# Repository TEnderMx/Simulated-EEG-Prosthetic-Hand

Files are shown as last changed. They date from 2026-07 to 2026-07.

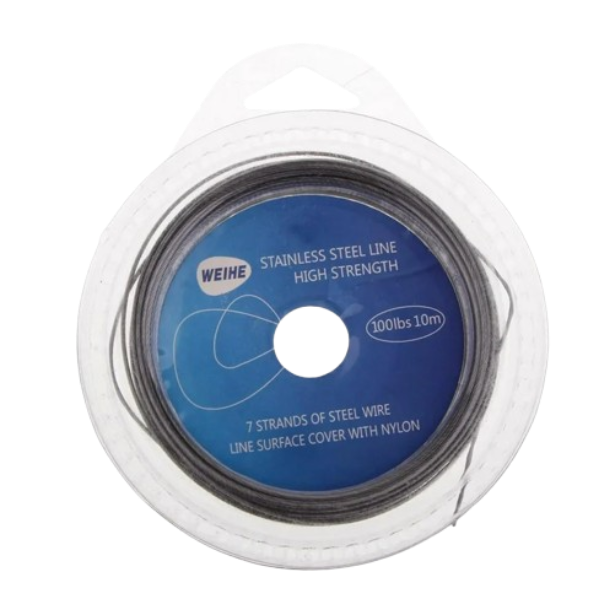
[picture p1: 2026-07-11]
Gallery/line.png

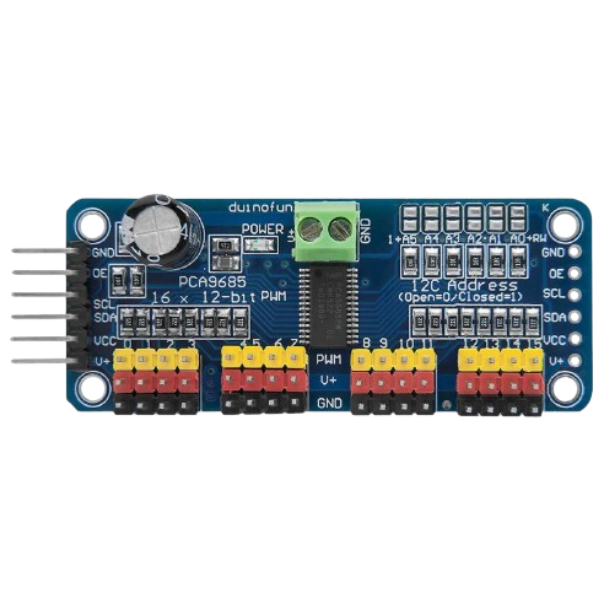
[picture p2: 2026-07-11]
Gallery/servocont.png

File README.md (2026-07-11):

<div align="center">

# 🧠 Simulated EEG BCI-Controlled Prosthetic Hand
**Translating Brain Signals into Physical Movement (Simulation Approach)**

[]()
[]()
[]()

*A Senior Graduation Project — Misr University for Science & Technology (MUST)*
<br>Faculty of Engineering | Biomedical Engineering Department

</div>

---

## 📖 Overview
This project introduces a **simulated Brain–Computer Interface (BCI)** system designed to assist upper-limb amputees. By decoding simulated neural activity, the system translates Motor Imagery (MI) into physical movement commands. The core innovation lies in a high-accuracy **MATLAB Signal Processing Pipeline** integrated with an **Artificial Neural Network (ANN)**, which drives a low-cost, high-torque prosthetic assembly via an Arduino UNO controller.

> **Note on Implementation:** Due to a technical malfunction with the planned EEG device preventing real signal acquisition, we adapted the project to use a highly sophisticated simulated BCI approach. This allowed us to maintain the complete software and hardware pipeline while simulating the neural input.

---

## ⚙️ Simulated System Architecture
To simulate the BCI input accurately, we integrated several advanced open-source tools to generate and stream neural-like data:

1. **Simulated Data Acquisition (MediaPipe):** We used Google's MediaPipe Hand Landmarker to capture 21 hand key points via camera tracking. This behavioral data acts as the basis for our simulated motor intentions.
2. **Simulated Data Processing (Neural Data Simulator - NDS):** We utilized the [Neural Data Simulator (NDS)](https://github.com/agencyenterprise/neural-data-simulator), an open-source Python package designed to generate real-time electrophysiology data. NDS translates the kinematics from MediaPipe into simulated 14-channel EEG-like waveforms (AF3, F7, F3, FC5, T7, P7, O1, O2, P8, T8, FC6, F4, F8, AF4).
3. **Data Streaming (Lab Streaming Layer - LSL):** The simulated neural data is streamed in real-time to MATLAB using [liblsl-Matlab](https://github.com/labstreaminglayer/liblsl-Matlab), effectively bridging the simulated signal source and our processing hub.
4. **Processing & Decoding (MATLAB):** MATLAB receives the LSL stream, processes the signals, and uses a Multi-layer Perceptron (MLP) Artificial Neural Network to classify the motor imagery.
5. **Actuation (Arduino & Hardware):** Classified commands are sent via Serial to an Arduino Uno, which drives high-torque metal gear servos (MG996R) using PWM to articulate the 3D-printed fingers.

---

## 🧠 Neural Network Performance
Our Artificial Neural Network (ANN) was trained using a back-propagation algorithm to map the complex, non-linear relationships of the simulated EEG features:
- **Average Classification Accuracy:** 82.1%
- **Training Convergence:** Demonstrated a consistent decline in Mean Squared Error (MSE) across epochs, indicating successful learning without overfitting.
- **Regression Analysis:** Achieved stable R-values across Training, Validation, and Testing phases, proving a strong correlation between targets and outputs.
- **Error Distribution:** Normal distribution of errors around zero, confirming the model is unbiased toward any specific output class.

---

## 🛠️ Hardware Integration
- **Microcontroller:** Arduino Uno R3 (ATmega328P, 16 MHz)
- **Actuators:** MG996R Metal Gear Servo Motors (11 kg/cm torque at 6V, 180° rotation)
- **Prosthetic Hand Design:** A lightweight, 3D-printed PLA assembly utilizing a bio-mimetic tendon-like structure. Nylon tension strings handle flexion, while a spring-return mechanism manages extension.

---

## 🚀 Future Roadmap
Our project successfully demonstrates a full-loop BCI solution (via simulation) translating neural motor imagery into mechanical grasping. To advance this foundation, we plan the following:
- [ ] **Real EEG Integration:** Transition from simulated data back to live EEG acquisition.
- [ ] **Sensory Feedback:** Integrate pressure sensors for tactile sensation.
- [ ] **Deep Learning:** Transition to LSTM networks for time-series optimization.
- [ ] **Portability:** Replace the PC processing hub with a Raspberry Pi for standalone use.
- [ ] **Cloud Integration:** Implement remote monitoring and subject training data logs.

---

## 👥 The Team
**Supervisor:** Dr. Islam A. Foad

---

## Special Credits and Huge Thanks to these amazing people:
**NDS:** https://github.com/agencyenterprise/neural-data-simulator/

**liblsl-Matlab:** https://github.com/labstreaminglayer/liblsl-Matlab/

**Prosthetic Hand Design:** https://inmoov.fr/

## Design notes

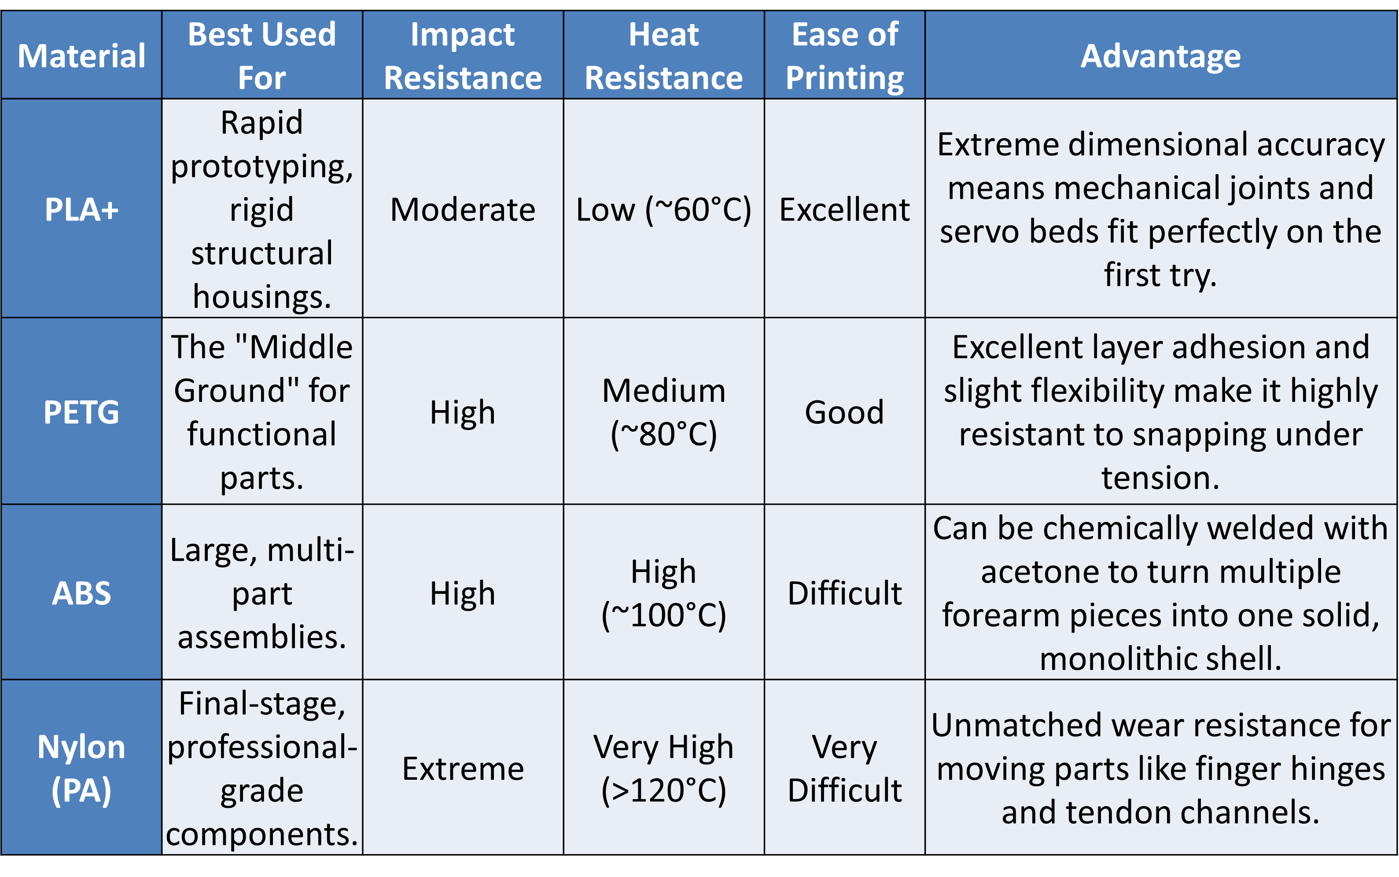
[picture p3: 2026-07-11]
Gallery/Picture4.png

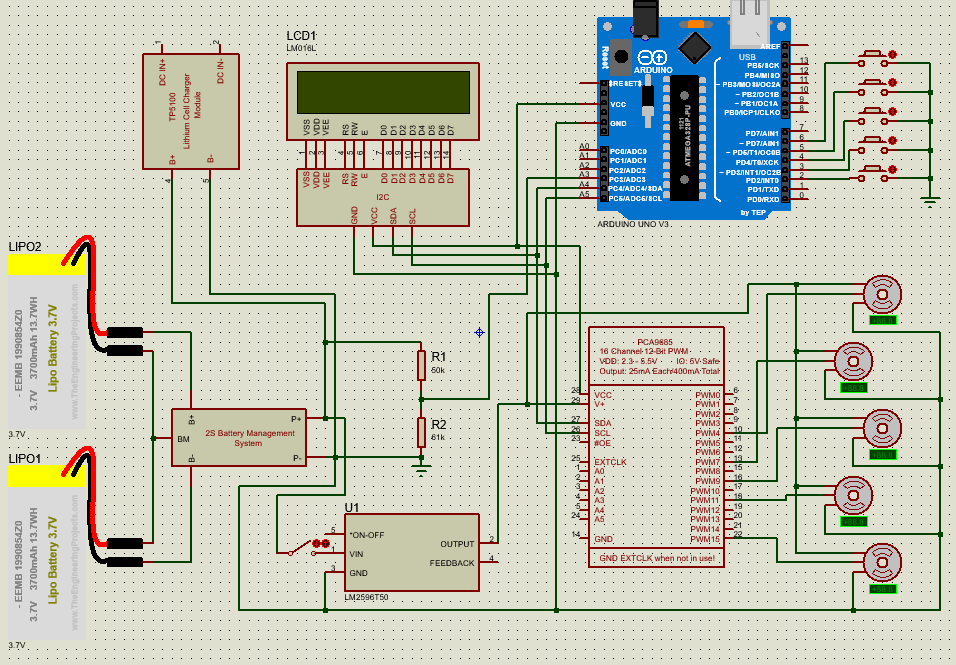
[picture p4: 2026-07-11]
Gallery/Circuit Diagram.png

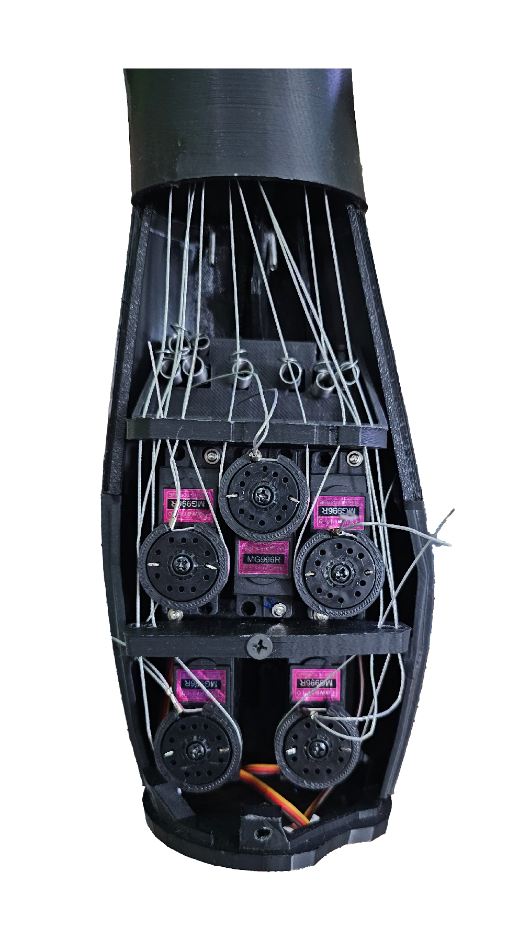
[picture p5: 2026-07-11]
Gallery/20260223_234325~1.png

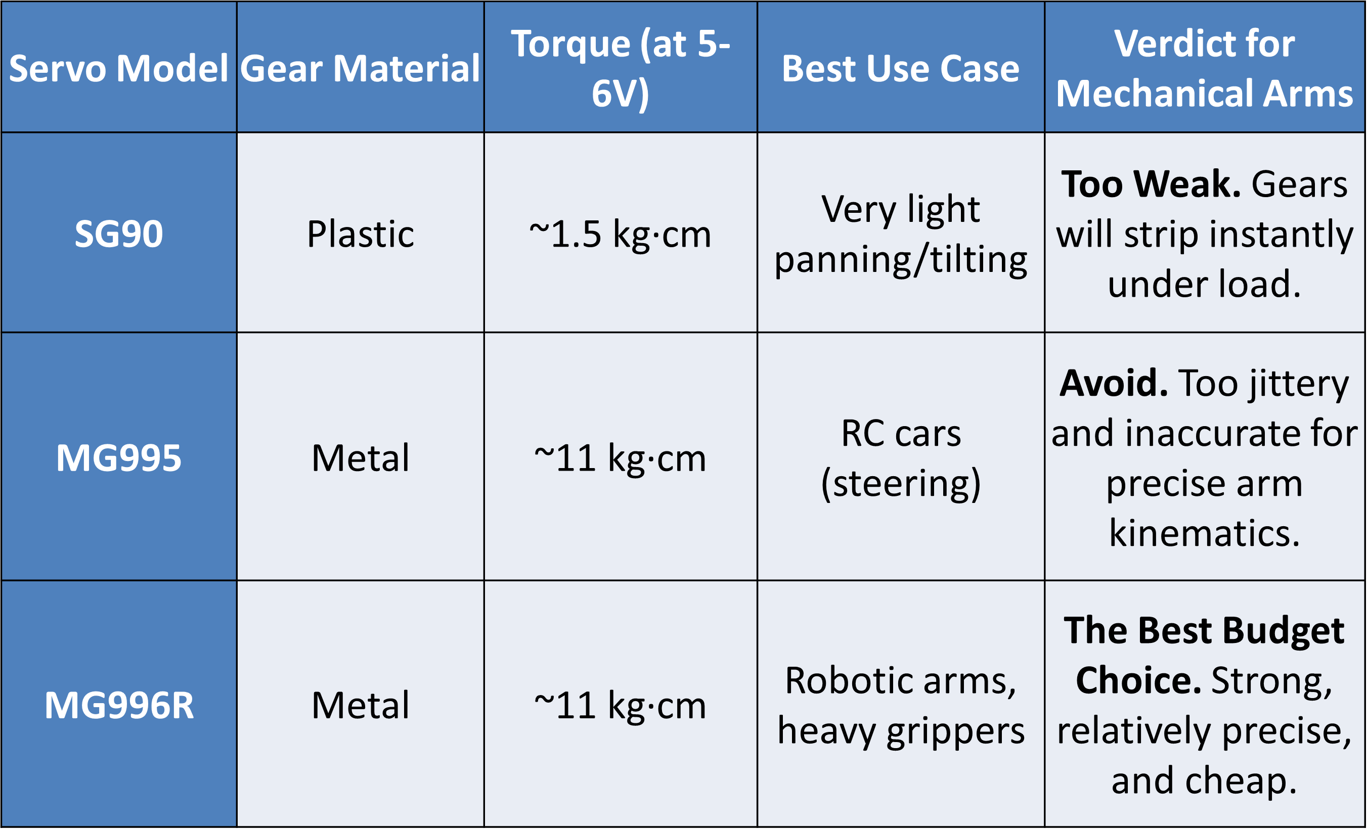
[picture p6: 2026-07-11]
Gallery/Picture3.png

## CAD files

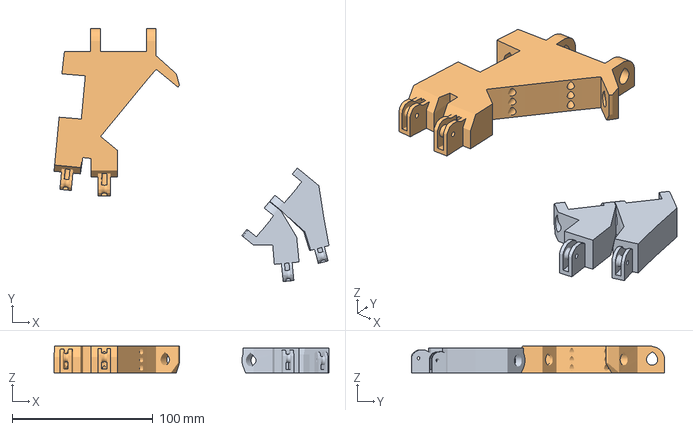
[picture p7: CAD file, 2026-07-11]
Hardware/3D Printer Files/Bambu Labs Files/Wrist.3mf
195.6 x 180.1 x 18.9 mm
WristsmallV4.stl
WristlargeV4.stl

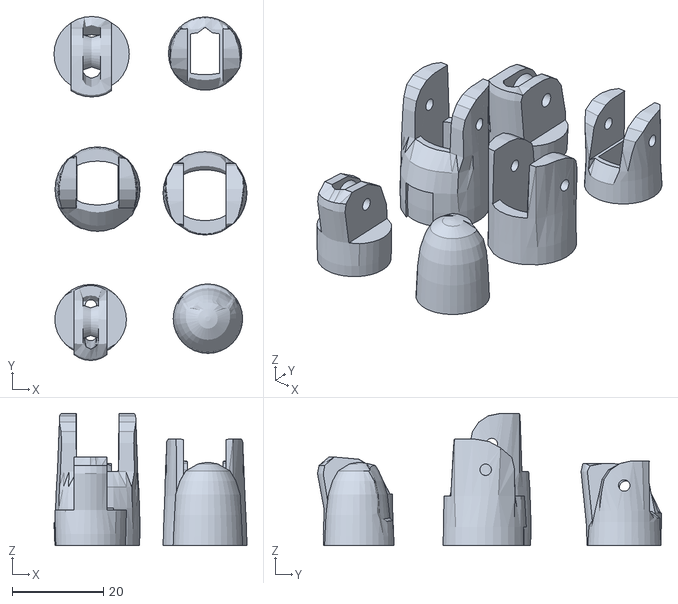
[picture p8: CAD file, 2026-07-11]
Hardware/3D Printer Files/Majeure3.stl
42.2 x 75.2 x 29.0

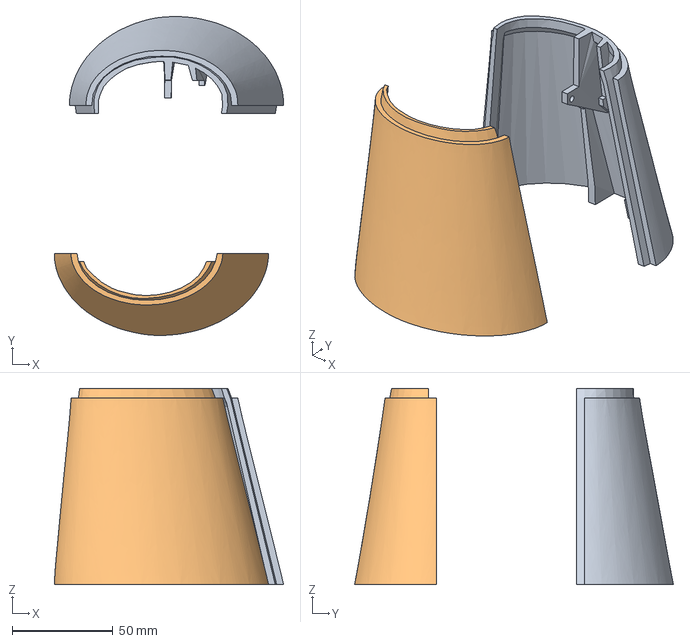
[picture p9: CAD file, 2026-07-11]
Hardware/3D Printer Files/Bambu Labs Files/Arm1.3mf
113.8 x 158.3 x 97.5 mm
robpart2V4.stl
robpart3V4.stl

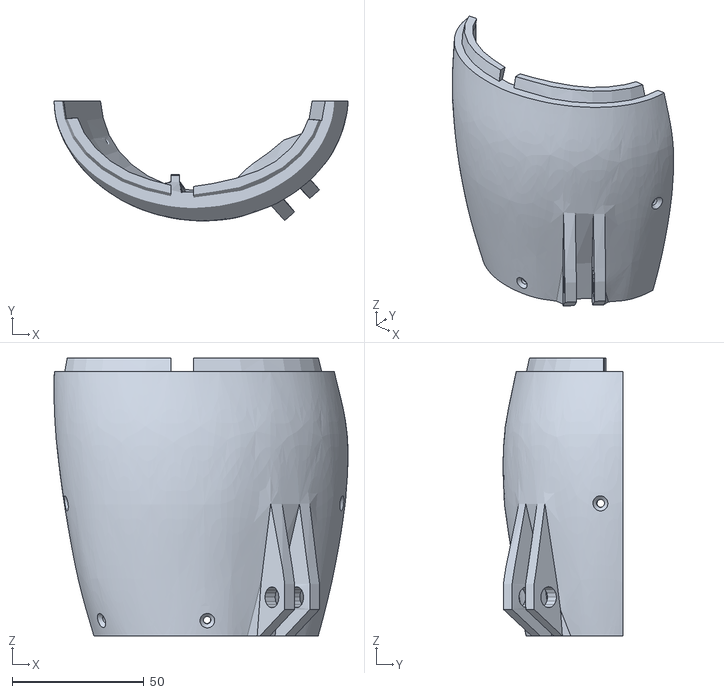
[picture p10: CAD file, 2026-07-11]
Hardware/3D Printer Files/robpart4V4.stl
111.8 x 45.5 x 105.6

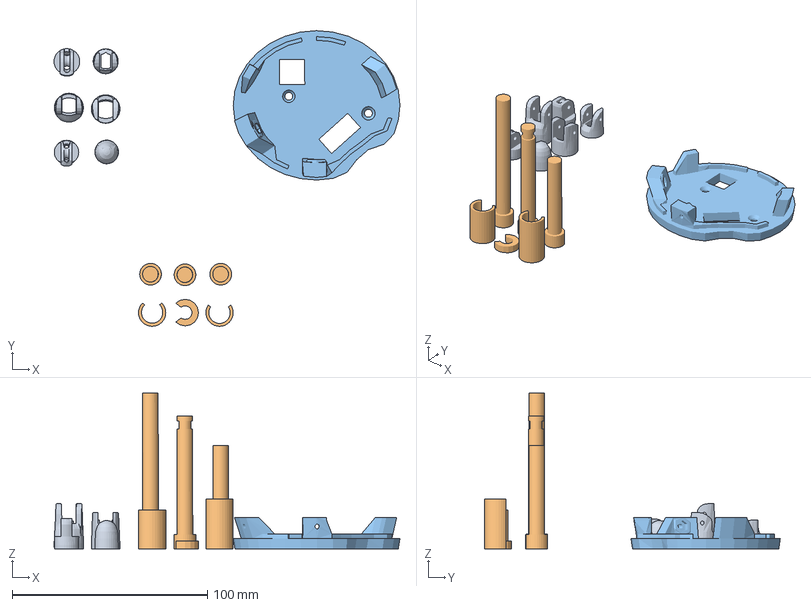
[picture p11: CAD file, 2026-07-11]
Hardware/3D Printer Files/Bambu Labs Files/Fingers2+ArmCap.3mf
177.3 x 151.5 x 79.9 mm
Auriculaire3.stl
Bolt_entretoise7.stl
robcap3V2.stl

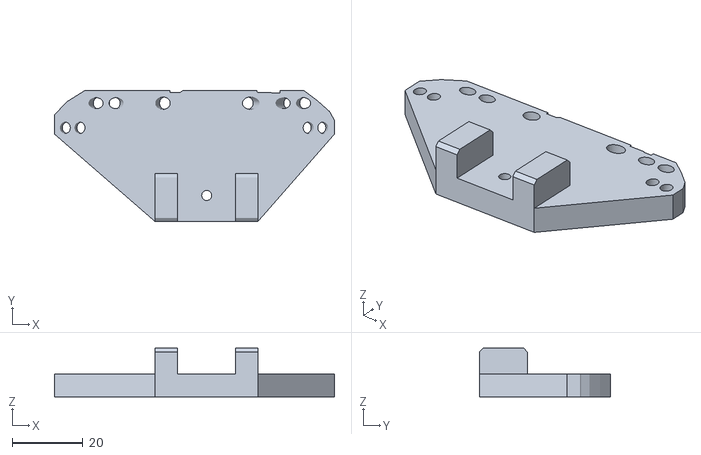
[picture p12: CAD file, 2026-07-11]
Hardware/3D Printer Files/RobCableFrontV3.stl
79.3 x 37.1 x 13.8

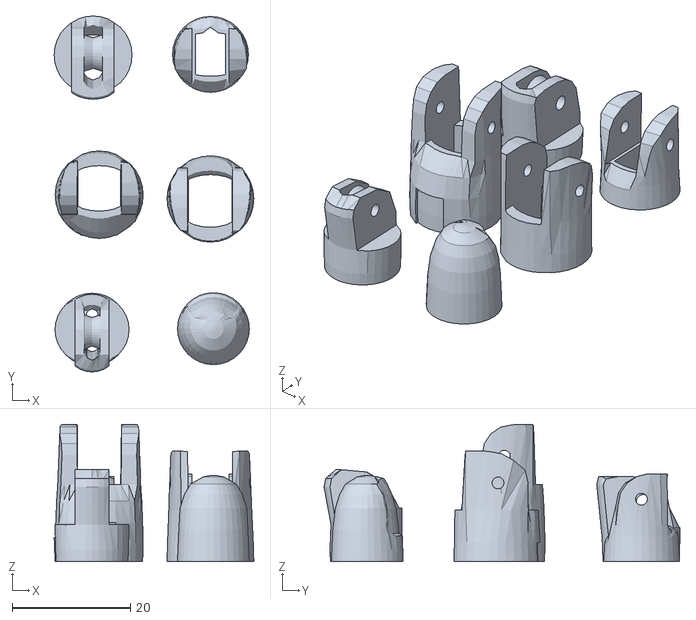
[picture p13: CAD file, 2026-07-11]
Hardware/3D Printer Files/Auriculaire3.stl
33.8 x 60.3 x 23.2

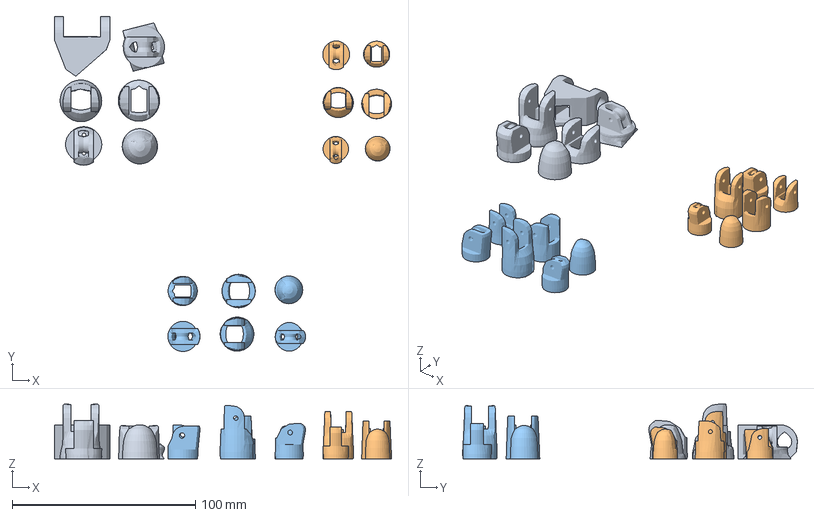
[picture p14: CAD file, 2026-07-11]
Hardware/3D Printer Files/Bambu Labs Files/Fingers1.3mf
184.1 x 182.9 x 29.8 mm
thumb5.stl
ringfinger3.stl
Majeure3.stl

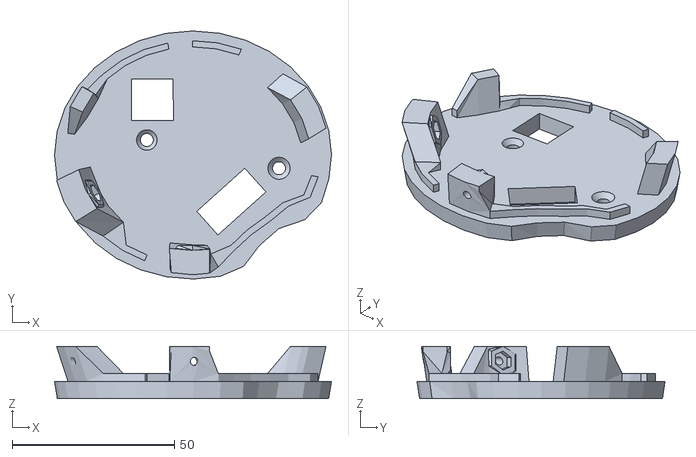
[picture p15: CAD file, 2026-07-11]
Hardware/3D Printer Files/robcap3V2.stl
85.5 x 76.5 x 16.2

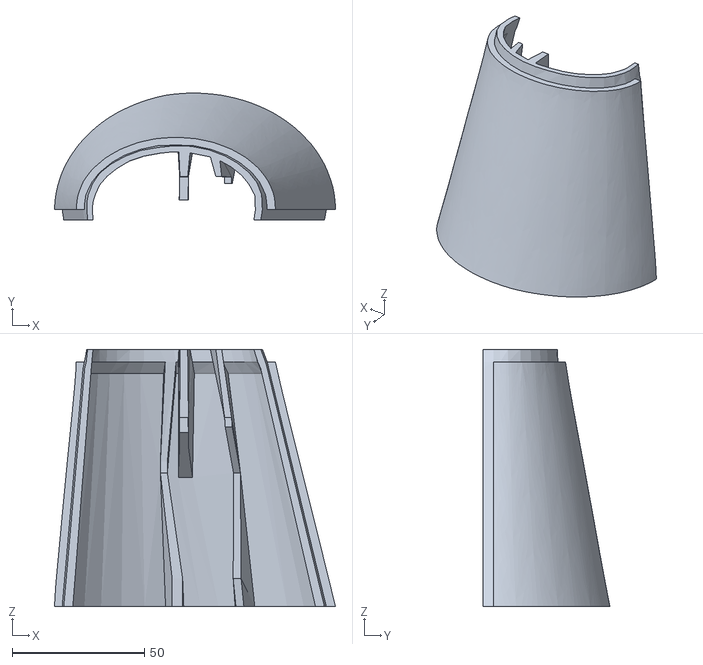
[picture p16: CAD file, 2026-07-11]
Hardware/3D Printer Files/robpart2V4.stl
106.4 x 48.1 x 97.5

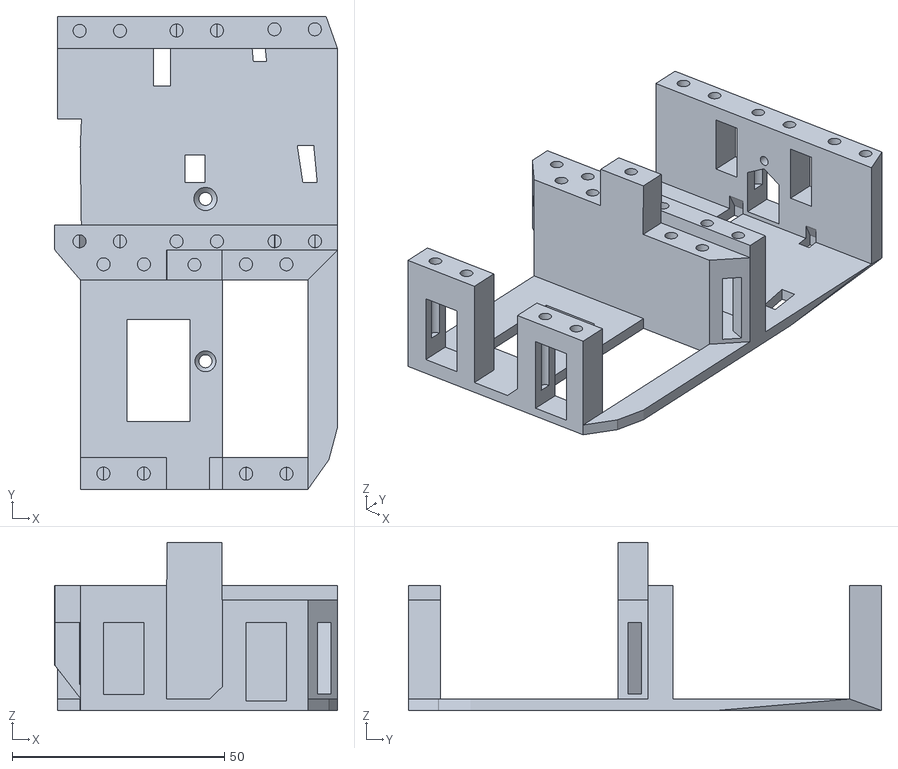
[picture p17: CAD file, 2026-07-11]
Hardware/3D Printer Files/RobServoBedV6.stl
66.7 x 111.6 x 39.7

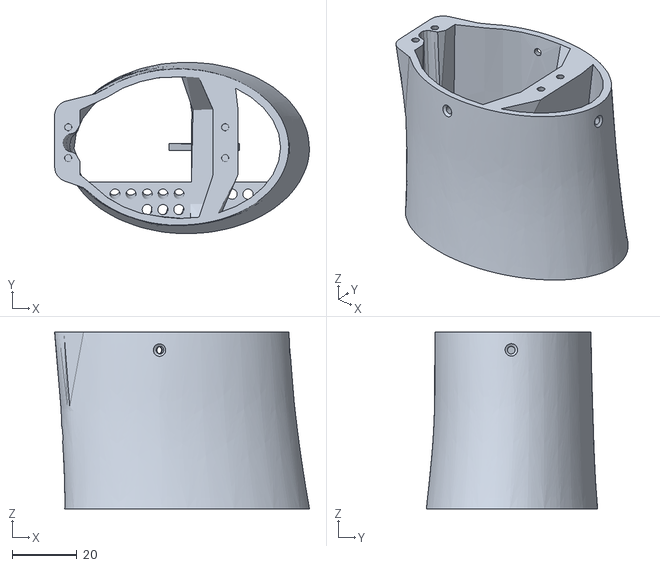
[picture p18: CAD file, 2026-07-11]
Hardware/3D Printer Files/RotaWrist1V4.stl
78.6 x 52.8 x 54.5

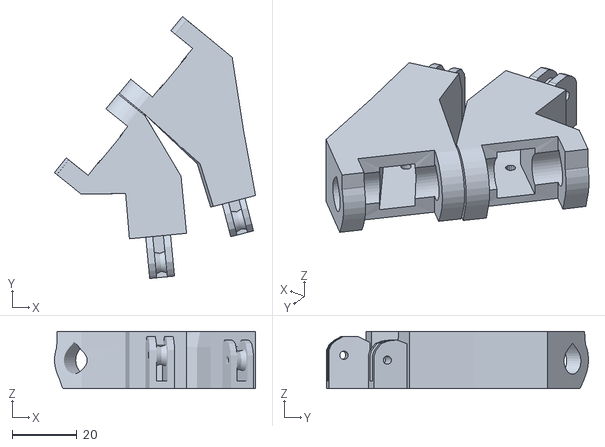
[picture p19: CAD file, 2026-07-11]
Hardware/3D Printer Files/WristsmallV4.stl
62.0 x 80.8 x 17.7

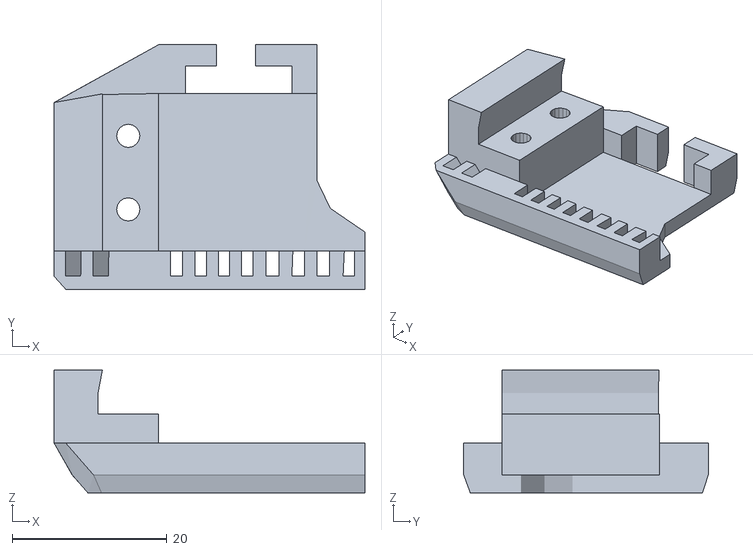
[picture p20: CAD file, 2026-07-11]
Hardware/3D Printer Files/CableHolderWristV5.stl
40.2 x 31.6 x 15.8

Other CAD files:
Hardware/3D Printer Files/Bambu Labs Files/Arm2.3mf
Hardware/3D Printer Files/RobCableBackV3.stl
Hardware/3D Printer Files/RobRingV3.stl
Hardware/3D Printer Files/RotaWrist3V3.stl
Hardware/3D Printer Files/Bolt.stl
Hardware/3D Printer Files/Bolt_entretoise7.stl
Hardware/3D Printer Files/Index3.stl
Hardware/3D Printer Files/RotaWrist2V3.stl
Hardware/3D Printer Files/TensionerRightV1.stl
Hardware/3D Printer Files/WristlargeV4.stl
Hardware/3D Printer Files/ringfinger3.stl
Hardware/3D Printer Files/robpart3V4.stl
Hardware/3D Printer Files/servo-pulleyX5.stl
Hardware/3D Printer Files/thumb5.stl

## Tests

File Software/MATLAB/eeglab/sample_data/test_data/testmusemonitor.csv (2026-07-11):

TimeStamp | Delta_TP9 | Delta_AF7 | Delta_AF8 | Delta_TP10 | Theta_TP9 | Theta_AF7 | Theta_AF8 | Theta_TP10 | Alpha_TP9 | Alpha_AF7 | Alpha_AF8 | Alpha_TP10 | Beta_TP9 | Beta_AF7 | Beta_AF8 | Beta_TP10 | Gamma_TP9 | Gamma_AF7 | Gamma_AF8 | Gamma_TP10 | RAW_TP9 | RAW_AF7 | RAW_AF8 | RAW_TP10 | AUX_RIGHT | Accelerometer_X | Accelerometer_Y | Accelerometer_Z | Gyro_X | Gyro_Y | Gyro_Z | HeadBandOn | HSI_TP9 | HSI_AF7 | HSI_AF8 | HSI_TP10 | Battery | Elements
2017-11-02 12:33:05.090 | 0.34463343 | -0.26432085 | -0.5435678 | 0.11157044 | 0.17629601 | -0.5999036 | -0.76048106 | 0.1363876 | 0.5730896 | -0.5712157 | -0.39508086 | 0.68532616 | 0.333399 | -0.7078538 | -0.5181579 | 0.6679262 | -0.6546381 | -1.0801746 | -0.8925843 | 0.457503 | 780.4762 | 877.98535 | 875.16486 | 757.50916 | 866.30035 | 0.4810791015625 | 0.12640380859375 | 0.8717041015625 | -0.171966552734375 | 1.614990234375 | -6.041259765625 | 1 | 1.0 | 1.0 | 1.0 | 1.0 | 17.41
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

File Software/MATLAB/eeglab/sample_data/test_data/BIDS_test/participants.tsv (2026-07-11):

participant_id | Gender | Age
sub-S1 | M | 32

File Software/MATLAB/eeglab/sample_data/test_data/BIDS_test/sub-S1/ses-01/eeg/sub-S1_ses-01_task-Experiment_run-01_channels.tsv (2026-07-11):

name | type | units
Fp1 | EEG | microV
AF7 | EEG | microV
AF3 | EEG | microV
F1 | EEG | microV
F3 | EEG | microV
F5 | EEG | microV
F7 | EEG | microV
FT7 | EEG | microV
FC5 | EEG | microV
FC3 | EEG | microV
FC1 | EEG | microV
C1 | EEG | microV
C3 | EEG | microV
C5 | EEG | microV
T7 | EEG | microV

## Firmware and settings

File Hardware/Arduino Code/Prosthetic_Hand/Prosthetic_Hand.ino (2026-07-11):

// INFORMATION
// -------------------------------------------
// Thumb = 4 == (4) Servo
// Index = 10 == (6) Servo
// Middle = 15 == (5) Servo
// Ring = 7 == (3) Servo
// Pinky = 12 == (2) Servo

// A5 == SCL
// A4 == SDA
// -------------------------------------------


#include <Adafruit_PWMServoDriver.h>  // PWM Servo Controller Library
#include <LiquidCrystal_I2C.h> // I2C LCD Library
#include <Wire.h> // Wire Library

Adafruit_PWMServoDriver pwm; // Define the Adafruit PWM Library as "pwm"
LiquidCrystal_I2C lcd(0x27,  16, 2); // Define the LiquidCrystal Library as "lcd" and setting dimenions

#define SERVOMIN 100 // 0 Degree
#define SERVOMAX 600 // 180 Degree
#define SERVOMID 350 // 90 Degree
#define SERVONUM 5 // Number of Servos

int servoPins[5] = {11, 7, 15, 12, 8}; // Define Servo Pins on PWM Controller (7, 8, 11, 12, 15)
int buttonPins[5] = {2, 3, 4, 5, 6}; // Define Button Pins on Arduino'
long loopcount = 0;

int VoltPerCent() { // Calculates the voltage of the batteries through a voltage divider
  int voltpercent;
  float value, voltage=0, voltmax=8.4, voltmin=6.4, voltageraw=0;
  value = analogRead(A2); // Read voltage divider

  voltageraw = value * (5.0/1023.0);
  voltage = voltageraw * ((50.0+61.0)/61.0); // Voltage Divider R1=50kOHM & R2=61kOHM
  voltpercent = (voltage-voltmin)*100.0/(voltmax - voltmin);

  return voltpercent;
}

void LoopCounter(int loops){ // Counts the number of Loops
  loopcount++;

  if(loopcount == loops){ // Execute after a set number of loops
    if(VoltPerCent() > 25){
      lcd.clear();
      lcd.setCursor(0,0); lcd.print("Battery: ");
      lcd.setCursor(9,0); lcd.print(VoltPerCent());
      lcd.setCursor(11,0); lcd.print("%");
      lcd.setCursor(0,1); lcd.print("Operating!");
    }
    else{
      lcd.clear();
      lcd.setCursor(0,0); lcd.print("Battery: ");
      lcd.setCursor(9,0); lcd.print(VoltPerCent());
      lcd.setCursor(11,0); lcd.print("%");
      lcd.setCursor(0,1); lcd.print("Please Charge!");
    }

    loopcount = 0;
  }
}

int AngleToPulse(int ang) { // Convert Angle to Pulses for Servo
  int pulse = map(ang, 0, 180, SERVOMIN, SERVOMAX); // Maps the Angles to Pulses
  return pulse;
}

void setup() {
  Serial.begin(9600); // Initialize Serial Monitor
  Serial.println("Start Test");

  pwm.begin(); // Initialize PWM Servo Controller
  pwm.setPWMFreq(50); // Set Servo Frequency

  lcd.init(); // Initialize LCD Screen
  lcd.backlight(); // Initialize LCD Backlight

  lcd.setCursor(0,0); lcd.print("Initializing"); // Write on Top Row
  lcd.setCursor(0,1); lcd.print("Please Wait..."); // Write on Bottom Row
  

  for(int i = 0; i < SERVONUM; i++){ // Reset All Servos to 0 Degree
    pwm.setPWM(servoPins[i], 0, AngleToPulse(0));
    delay(1000);
  }

  lcd.clear(); lcd.print("Welcome!"); // Clear LCD and Print
  delay(750);
  lcd.clear();

  LoopCounter(1);

  // Define Pins on Arduino For Buttons
  pinMode(2, INPUT_PULLUP);
  pinMode(3, INPUT_PULLUP);
  pinMode(4, INPUT_PULLUP);
  pinMode(5, INPUT_PULLUP);
  pinMode(6, INPUT_PULLUP);
}

void loop() {
  LoopCounter(50);

  int incomingAngle = Serial.read();

  // for (int i = 0; i < SERVONUM; i++) {  // Control Fingers with 5 Buttons
  //   if (digitalRead(buttonPins[i]) == HIGH) {
  //     pwm.setPWM(servoPins[i], 0, AngleToPulse(0)); // released
  //     Serial.println("Extend");
  //   }
  //   else if(digitalRead(buttonPins[i]) == LOW) {
  //     pwm.setPWM(servoPins[i], 0, AngleToPulse(130));   // pressed
  //     Serial.println("Curl");
  //   }
  // }

  if (Serial.available() >= 0) {
    if (incomingAngle == 90) {
      pwm.setPWM(servoPins[3], 0, AngleToPulse(130));
      Serial.println(incomingAngle);
    }
    else if (incomingAngle == 0){
      pwm.setPWM(servoPins[3], 0, AngleToPulse(0));
    }
  Serial.println(incomingAngle);
  }

  delay(25);

}
